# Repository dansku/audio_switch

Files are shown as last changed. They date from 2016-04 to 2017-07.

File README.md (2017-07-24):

# Audio Switch PCB 

A simple electronics project developed using EagleCad to switch two audio sources.

**Full blog post for the project https://www.danielandrade.net/2016/04/10/build-a-3-5mm-audio-switch/**

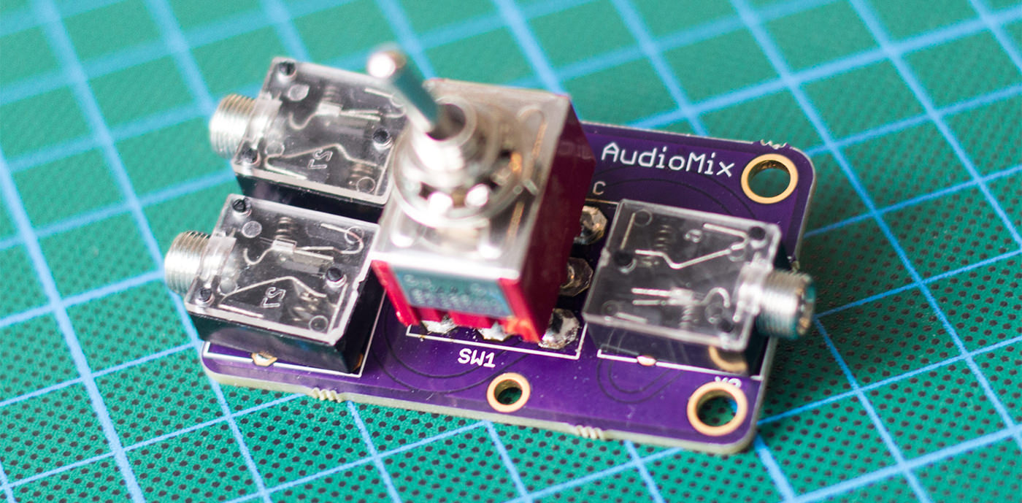
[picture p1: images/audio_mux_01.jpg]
pcb picture


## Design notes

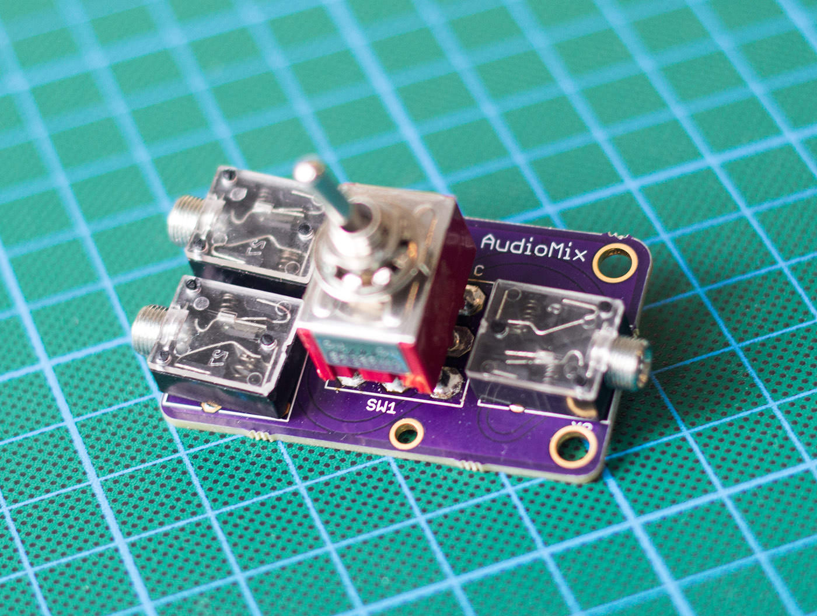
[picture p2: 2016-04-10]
images/audio_mux_02.jpg

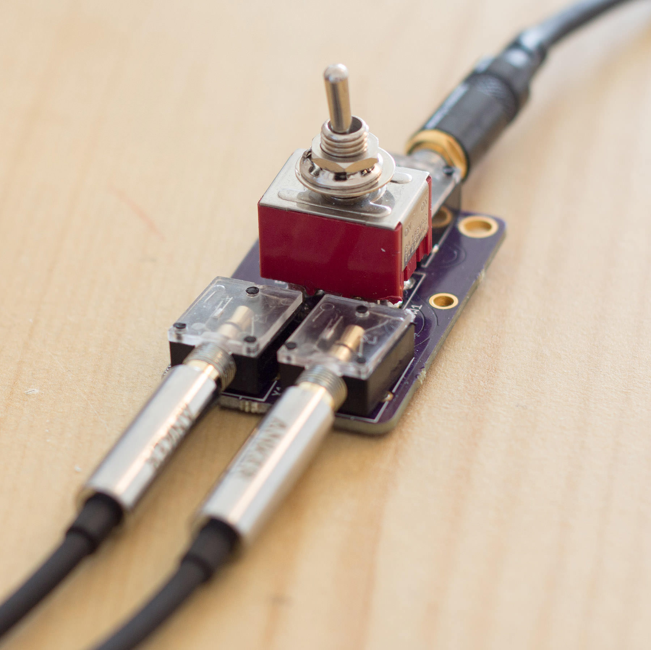
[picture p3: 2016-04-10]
images/audio_mux_05.jpg

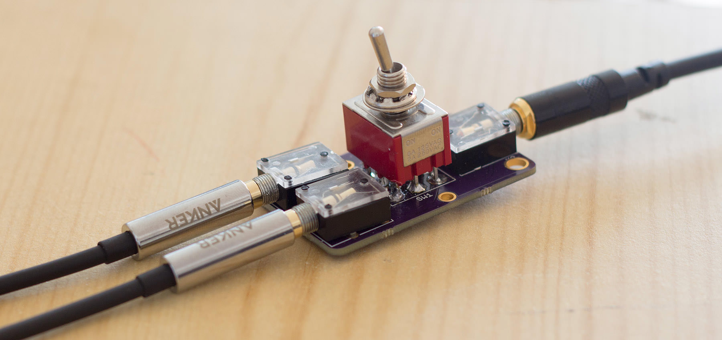
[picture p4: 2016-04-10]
images/audio_mux_04.jpg

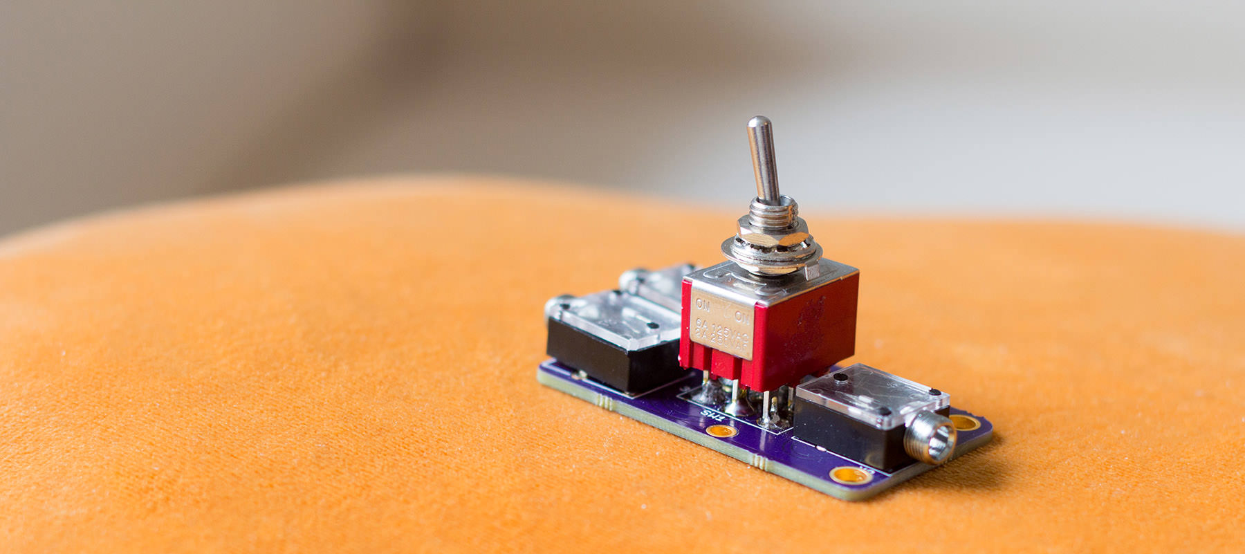
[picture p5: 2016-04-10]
images/audio_mux_06.jpg

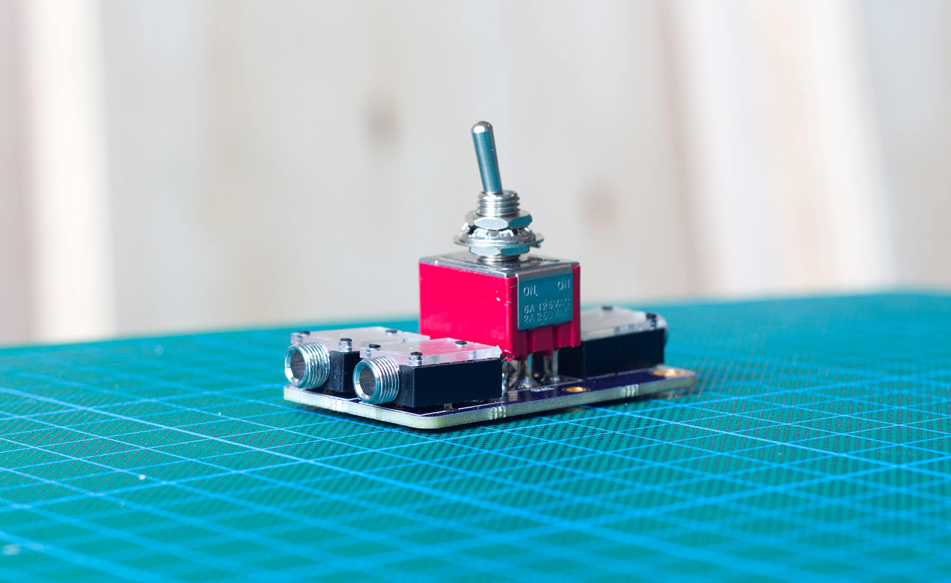
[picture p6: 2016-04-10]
images/audio_mux_03.jpg

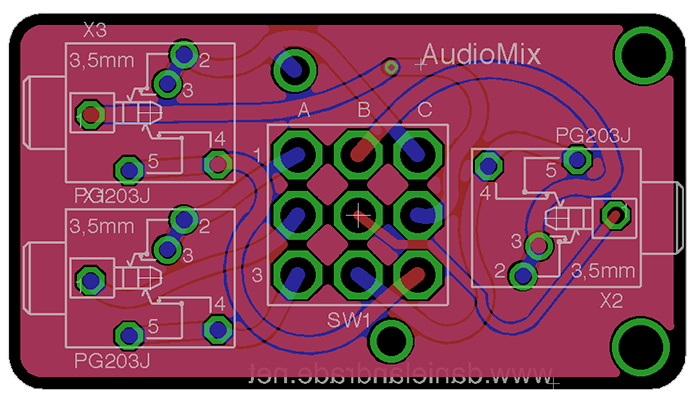
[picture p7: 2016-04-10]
images/pcb.png

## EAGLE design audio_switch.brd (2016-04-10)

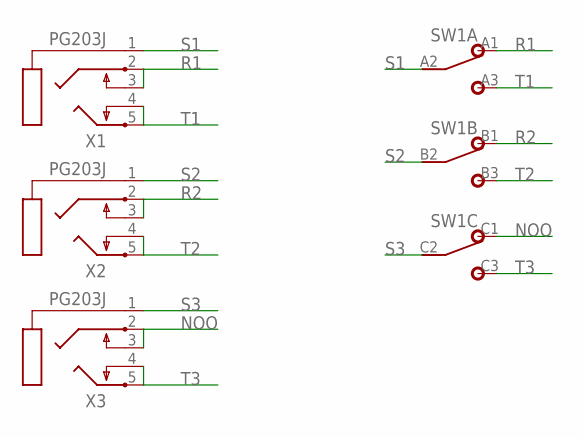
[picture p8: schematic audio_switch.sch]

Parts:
SW1: 3PDT
X1, X2, X3: PG203J

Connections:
NOO: SW1.C1 (1), X3.2, X3.3
R1: SW1.A1 (1), X1.2, X1.3
R2: SW1.B1 (1), X2.2, X2.3
S1: SW1.A2 (2), X1.1
S2: SW1.B2 (2), X2.1
S3: SW1.C2 (2), X3.1
T1: SW1.A3 (3), X1.4, X1.5
T2: SW1.B3 (3), X2.4, X2.5
T3: SW1.C3 (3), X3.4, X3.5

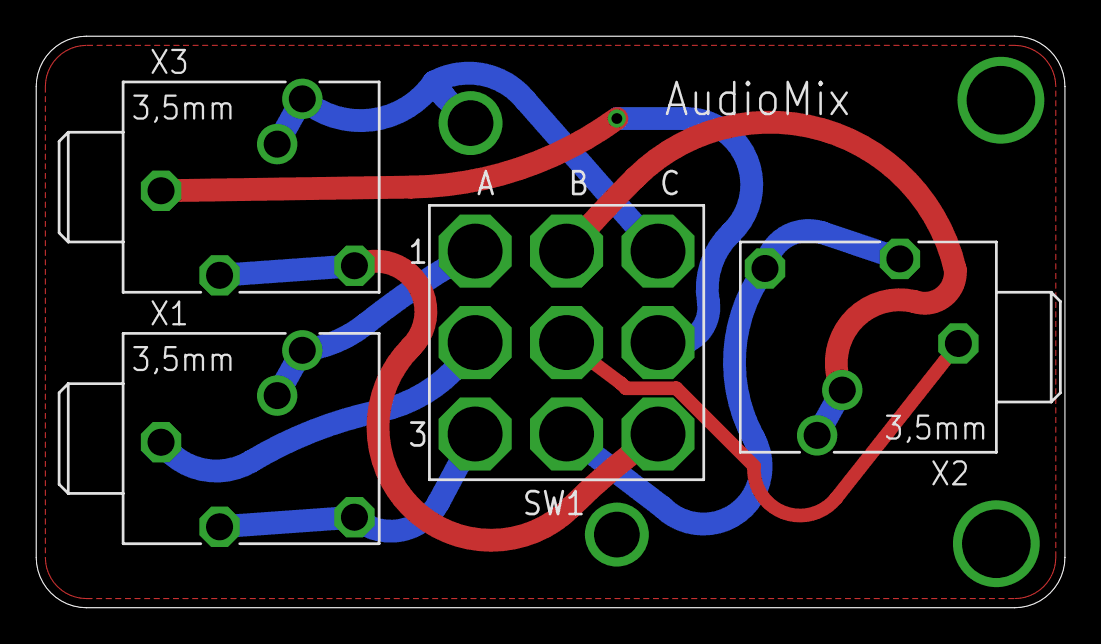
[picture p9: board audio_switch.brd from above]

Board: 2 copper layers, 57.1 x 31.8 mm, 4 parts (0 on the bottom side), 9 nets.

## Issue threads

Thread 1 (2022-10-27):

Grounds not connected together

Audioswitch, 2022-10-27:
The way the gerber is currently laid out has each ground on its own pin instead of all being tied together.

The effect of this is that when you switch between outputs there is an audible pop/thump.

Fixed gerber:
[Gerber file.zip](https://github.com/dansku/audio_switch/files/9874617/Gerber.file.zip)

dansku, 2022-10-27:
thank you!!
